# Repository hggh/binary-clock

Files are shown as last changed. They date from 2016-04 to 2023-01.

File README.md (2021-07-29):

# Arduino - binary clock (BCD) with WS2812B

Binary Clock mit WS2812b LED strips

## Bauteile

 * Schwarzes festes Papier (Pappe) Lichtstreifen
 * Ikea Ribba Rahmen, 50x50cm
 * Plexiglas 45% Lichtdurchlässigkeit 50x50cm 2mm
 * schwarze Klebefolie
 * Arduino (Uno oder Nano)
 * 40x WS2812b LEDs (Stips 60 LEDs/m)
 * RTC Modul
 * DCF77 Modul

## Hardware

 * connect color change button to GND and digital pin 6
 * connect led brightness button to GND and digital pin 5
 * connect WS2812b Data In to digital pin 9
 * connect RV8523 RTC to A4(SDA) and A5(SCL)
 * connect DCF77 module to digital pin 2 and digital pin 0

## Weitere Bilder vom Bau

[Weitere Bilder](Pics.md)

## Bild

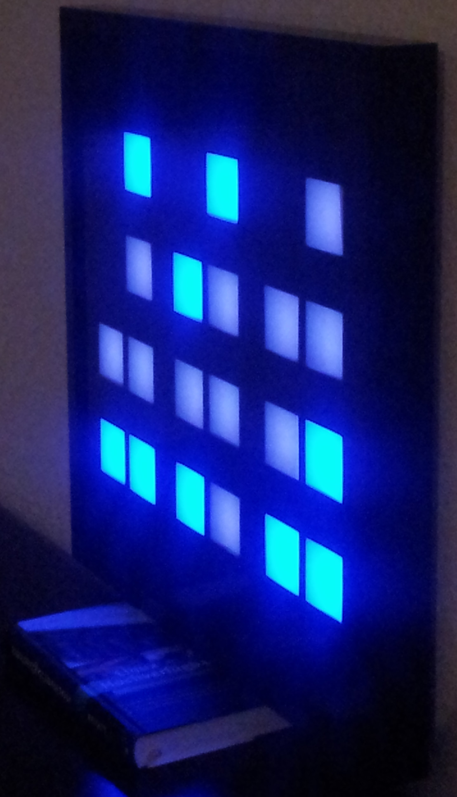
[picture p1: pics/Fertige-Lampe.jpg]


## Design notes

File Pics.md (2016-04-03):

# Bilder vom Bau

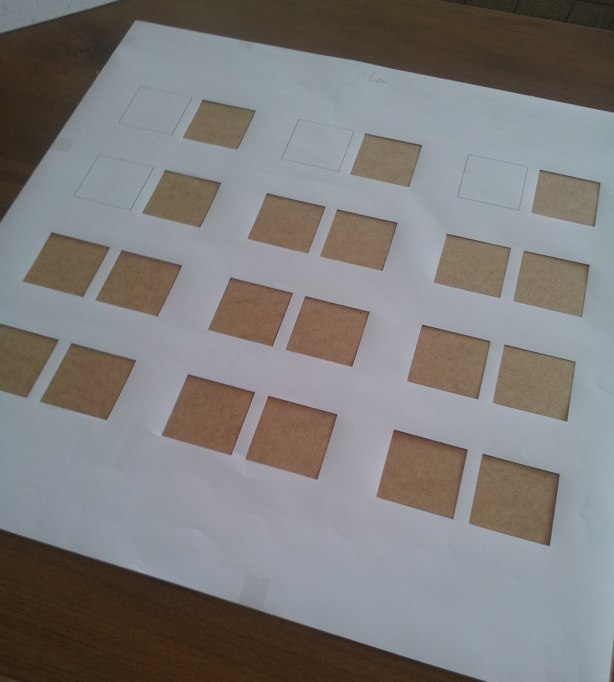
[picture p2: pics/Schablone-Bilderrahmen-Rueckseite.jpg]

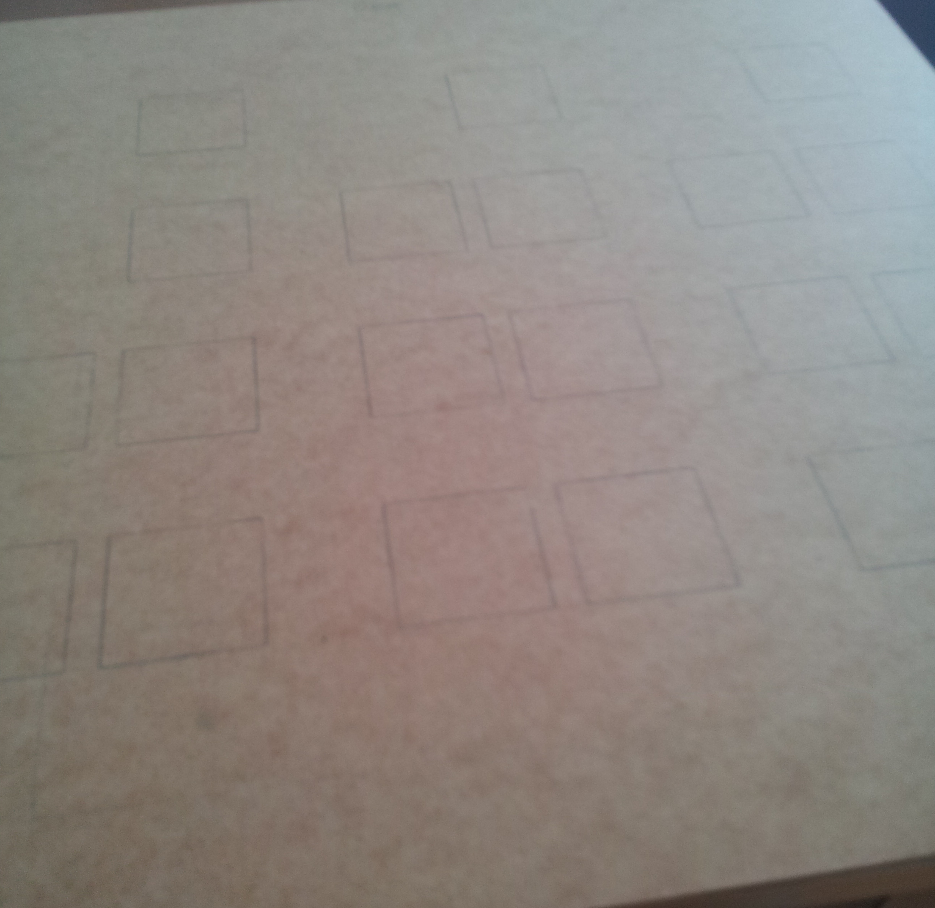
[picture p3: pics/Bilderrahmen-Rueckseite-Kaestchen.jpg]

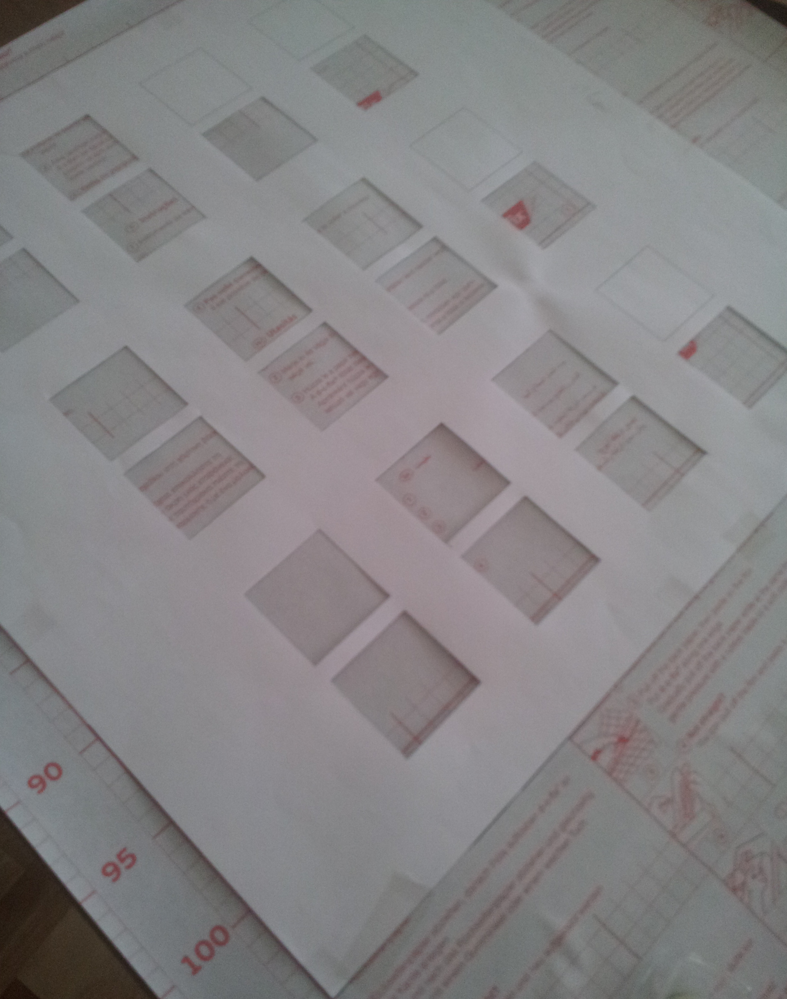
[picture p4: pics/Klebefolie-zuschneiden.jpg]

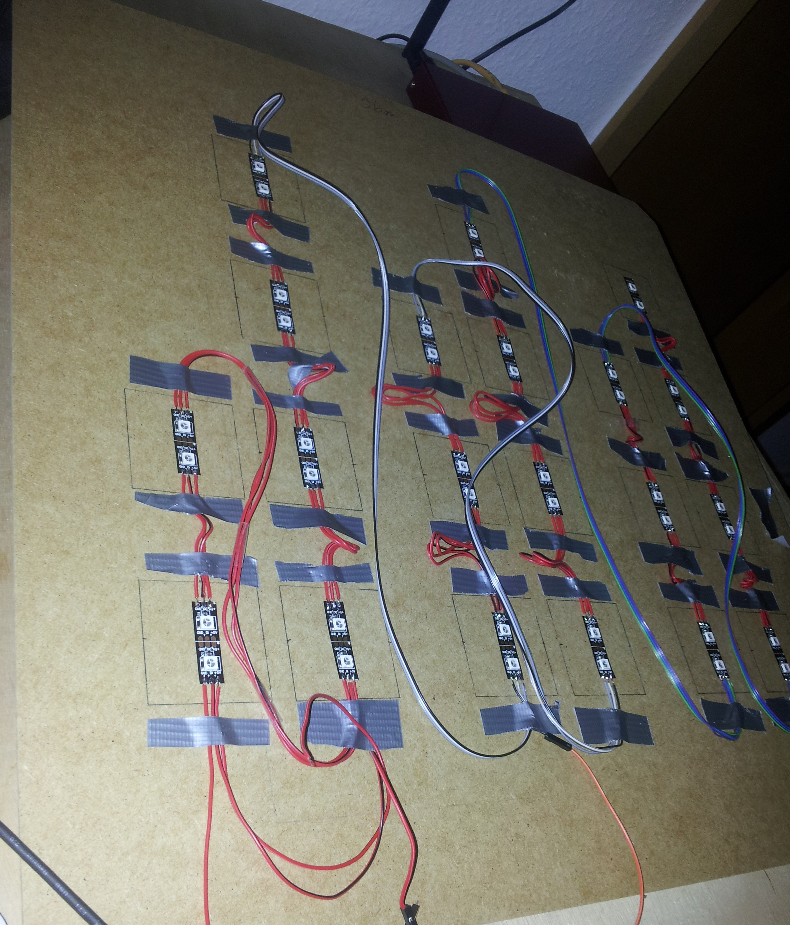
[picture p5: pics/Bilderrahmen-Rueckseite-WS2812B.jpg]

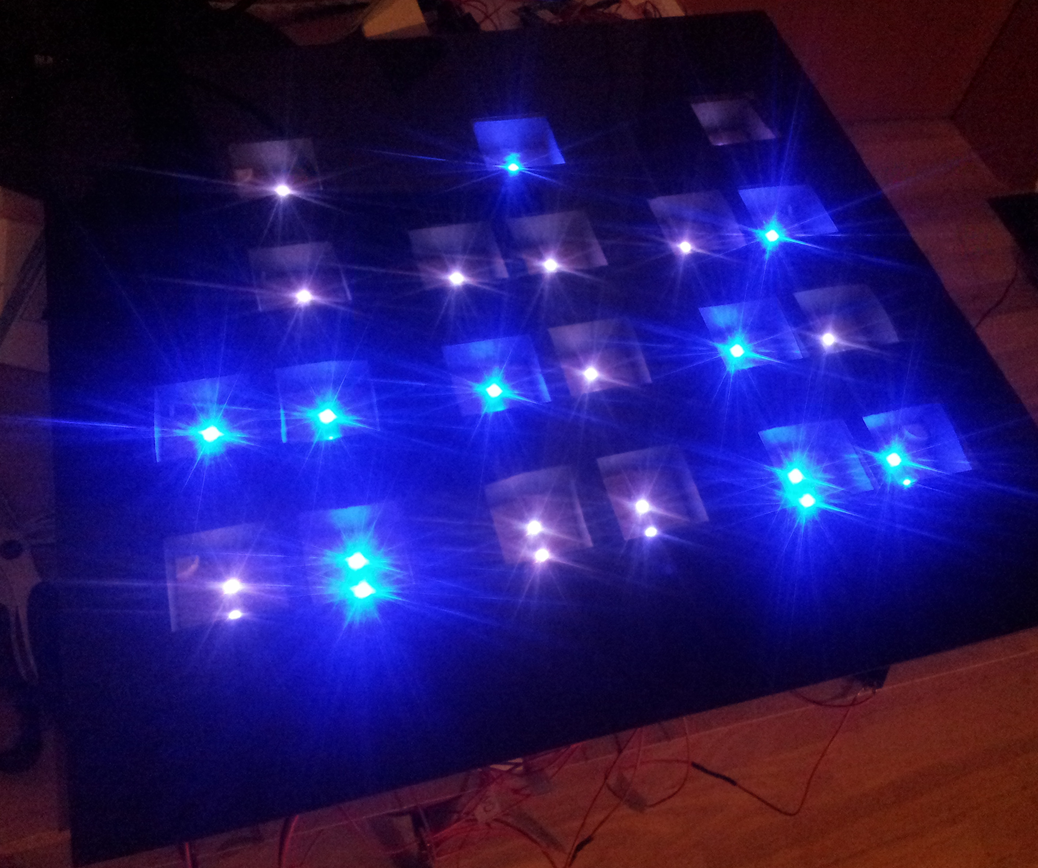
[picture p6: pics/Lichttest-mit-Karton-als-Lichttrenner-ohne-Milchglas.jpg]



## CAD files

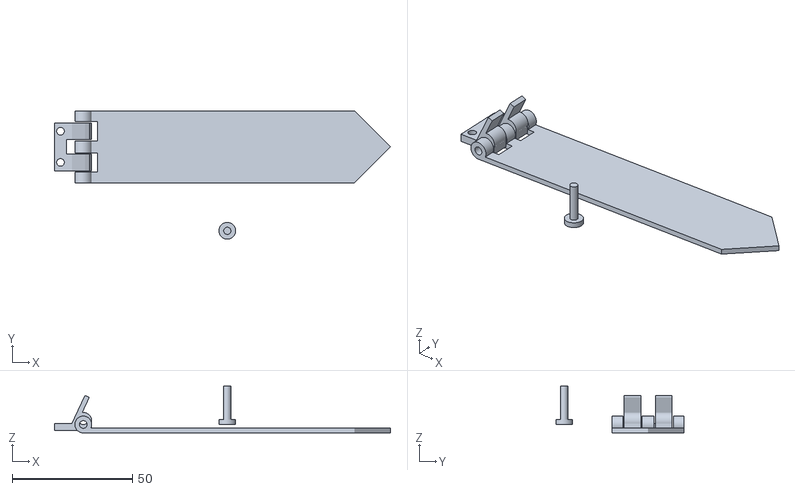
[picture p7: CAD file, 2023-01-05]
3d/holder-back.stl
140.0 x 53.5 x 19.5

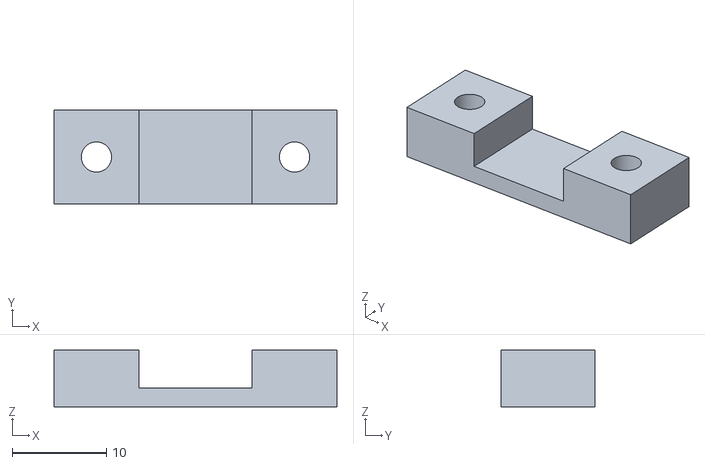
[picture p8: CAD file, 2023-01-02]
3d/ButtonHolder.stl
30.0 x 10.0 x 6.00

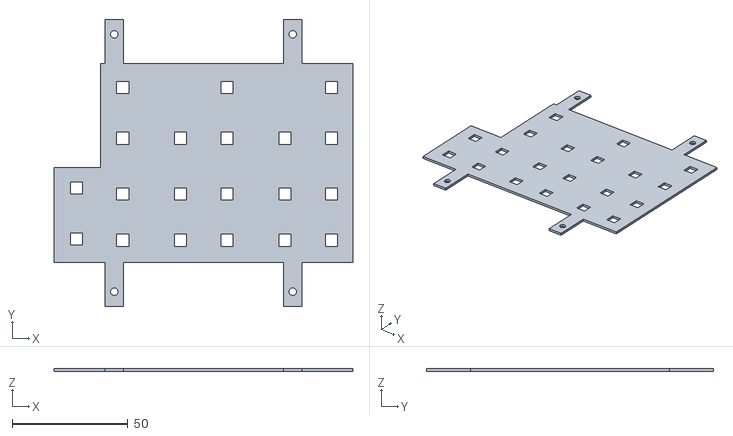
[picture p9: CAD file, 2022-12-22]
3d/led-mounting.stl
129.0 x 124.0 x 1.20

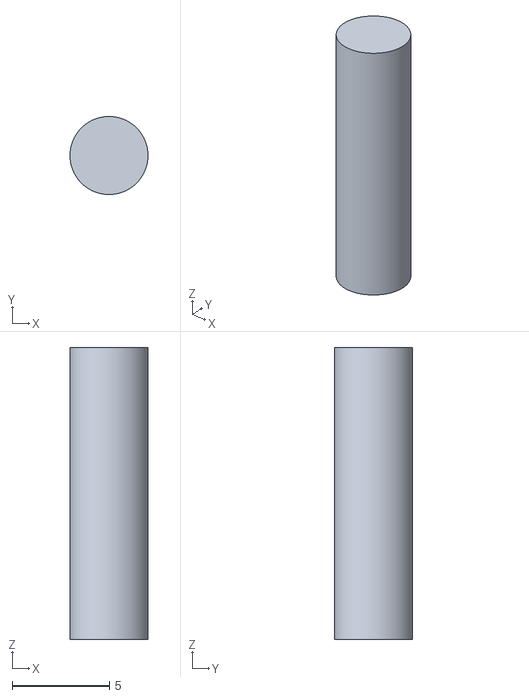
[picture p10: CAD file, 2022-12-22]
3d/wood-connector.stl
4.01 x 4.01 x 15.0

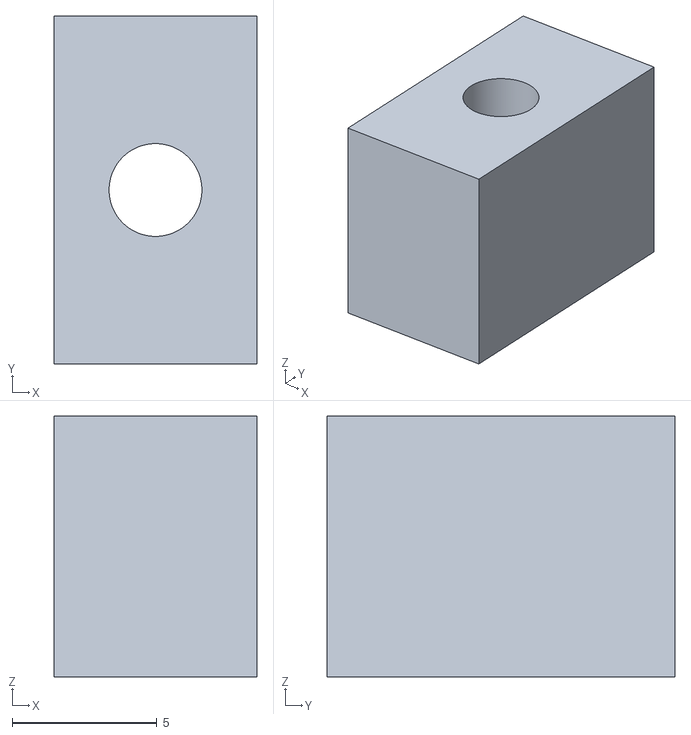
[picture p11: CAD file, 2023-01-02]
3d/led-mounting-screw-holder.stl
7.00 x 12.0 x 9.00

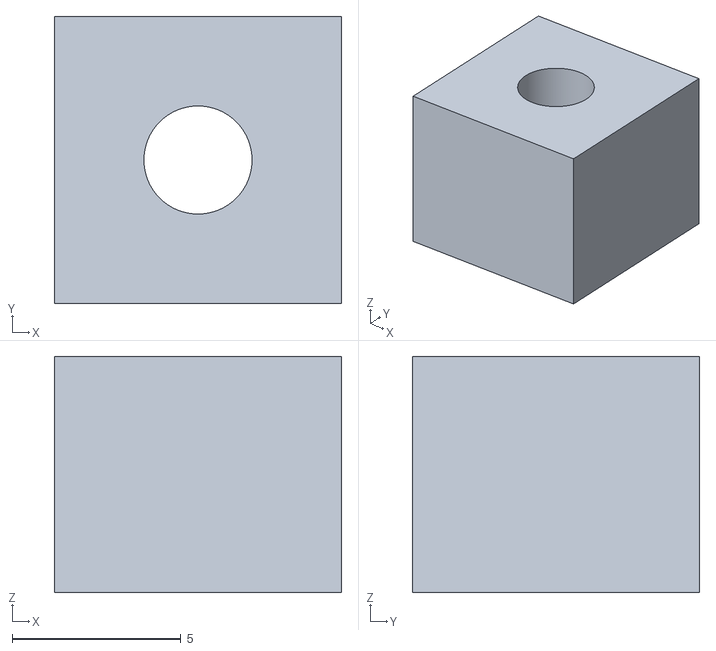
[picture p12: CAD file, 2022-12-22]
3d/screw-holder-inside.stl
8.50 x 8.50 x 7.00

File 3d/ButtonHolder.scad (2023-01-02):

//button 12mm
// hoch = 4mm


difference() {
    cube([30, 10, 2  + 4]);
    translate([9, 0, 2]) cube([12, 10, 10]);
    
    translate([4.5, 5, 0]) {
        cylinder(d=3.2, h=8, $fn=190);
        cylinder(r = 5.5 / 2 / cos(180 / 6) + 0.05, h=3, $fn=6);
    }
    translate([25.5, 5, 0]) {
        cylinder(d=3.2, h=8, $fn=190);
        cylinder(r = 5.5 / 2 / cos(180 / 6) + 0.05, h=3, $fn=6);
    }
}

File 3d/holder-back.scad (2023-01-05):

$fn=190;

difference() {
    union() {
        rotate([270, 0, 0]) cylinder(d=7, h=30);
        translate([0, 0, -3.5]) cube([115 - 2, 30, 2]);
    }
    rotate([270, 0, 0]) cylinder(d=3.2, h=30);
    
    translate([-10, 5-0.5, -5]) cube([16, 7+1, 10]);
    translate([-10, 30 - 8 -5 +0.5, -5]) cube([16, 7+1, 10]);
}

translate([115-2, 0, -3.5]) rotate([0, 0, 45])cube([21.21,21.21, 2]);



translate([60, -20, 0]) {
    cylinder(d=3, h=14 +2);
    cylinder(d=7, h=2);
}


translate([-5, 0, -2.5]) {
    difference() {
        union() {
            translate([-2, 5, 0]) cube([10.4, 7, 3]);
            translate([5, 5, 4]) rotate([270, 0, 0]) cylinder(d=7, h=7);
            translate([5, 30 - 5 -7, 4]) rotate([270, 0, 0]) cylinder(d=7, h=7);
            translate([-2, 30 - 5 -7, 0]) cube([10.4, 7, 3]);
            
        }
        translate([5, 5, 4]) rotate([270, 0, 0]) cylinder(d=3.2, h=7);
        translate([5, 30 - 5 -7, 4]) rotate([270, 0, 0]) cylinder(d=3.2, h=7);
        
        
    }
    translate([2, 5, 2]) {
        rotate([0, -65, 0]) cube([13, 7, 2]);
        translate([0, 13, 0])
        rotate([0, -65, 0]) cube([13, 7, 2]);
    }
    translate([-7, 5, 0]) {
        difference() {
            cube([5, 20, 3]);
            // Montage M3
            translate([2.5, 3.5, 0]) cylinder(d=3.2, h=10);
            translate([2.5, 3.5 + 7 +5+1, 0]) cylinder(d=3.2, h=10);
        }
    }

}

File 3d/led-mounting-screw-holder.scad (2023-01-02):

$fn=190;

difference() {
    cube([7, 12, 9]);
    translate([3.5, 6, 0]) {
        cylinder(d=3.2, h=10);
        rotate([0, 0, 30])cylinder(r = 5.5 / 2 / cos(180 / 6) + 0.05, h=4, $fn=6);
    }
}

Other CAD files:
3d/led-mounting.scad
3d/screw-holder-inside.scad
3d/wood-connector.scad

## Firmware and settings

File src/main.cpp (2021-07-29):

#include <Arduino.h>
#include <TimeLib.h>
#include <Wire.h>

#include <RV8523.h>
#include <FastLED.h>
#include <Bounce2.h>
#include <DCF77.h>

//#define HAS_DCF77

#define LED_CLOCK_COUNT 40   // all LEDs
#define BUTTON_BRIGHTNESS 5 // digital pin 5
#define BUTTON_COLOR 6 // digital pin 6
#define LED_CLOCK_PIN  9     // digital data pin
#define DCF_PIN 2            // Digital Pin Connection pin to DCF 77 device
#define DCF_INTERRUPT 0      // Interrupt number associated with pin

DCF77 DCF = DCF77(DCF_PIN, DCF_INTERRUPT);
RV8523 rtc;
CRGB clock_leds[LED_CLOCK_COUNT];

Bounce2::Button button_brightness = Bounce2::Button();
Bounce2::Button button_color = Bounce2::Button();

const CRGB::HTMLColorCode colors[35] = { CRGB::Crimson,CRGB::Red,CRGB::DarkRed,CRGB::DeepPink,CRGB::OrangeRed,CRGB::Orange,CRGB::Gold,CRGB::Yellow,CRGB::Violet,CRGB::Navy,CRGB::RosyBrown,
CRGB::Fuchsia,CRGB::MediumOrchid,CRGB::BlueViolet,CRGB::Purple,CRGB::Indigo,CRGB::DarkSlateBlue,CRGB::GreenYellow,CRGB::Lime,CRGB::MediumSpringGreen,CRGB::ForestGreen,CRGB::DarkGreen,
CRGB::LightSeaGreen,CRGB::Teal,CRGB::Cyan,CRGB::CadetBlue,CRGB::SteelBlue,CRGB::SkyBlue,CRGB::Blue,CRGB::DarkBlue,CRGB::Chocolate,CRGB::SaddleBrown,CRGB::Maroon,CRGB::DarkSlateGray,CRGB::Brown };

/*
 * Global variables for Loop
 */
time_t time_old;
uint8_t led_brightness = 255;
uint8_t led_color_brightness = 80;
uint8_t led_color_index = 0;
boolean update_leds = false;
CRGB::HTMLColorCode led_color = CRGB::DarkBlue;

/*
 * Set the RTC timer from the time_t struct
 */
void rtc_set_time(time_t time_c) {
  rtc.stop();
  rtc.set(
    second(time_c),
    minute(time_c),
    hour(time_c),
    day(time_c),
    month(time_c),
    year(time_c)
  );
  rtc.start();
}

/*
 * Get the RTC time and return time_t
 */
time_t rtc_get_time() {
  tmElements_t tm;
  uint8_t sec, min, hour, day, month;
  uint16_t year;

  rtc.get(&sec, &min, &hour, &day, &month, &year);

  tm.Second = sec;
  tm.Minute = min;
  tm.Hour = hour;
  tm.Day = day;
  tm.Month = month;
  tm.Year = (year - 1970);
  return makeTime(tm);
}

/*
 * some nice loopings
 */
void leds_do_looping() {
  for (uint8_t i = 0; i < 4; i++) {
    for (uint8_t dot = 0; dot < LED_CLOCK_COUNT; dot++) {
      clock_leds[dot] = CRGB::Blue;
      FastLED.show();
      clock_leds[dot] = CRGB::Red;
      delay(10);
    }
    FastLED.clear();
    FastLED.show();
  }
}

void setup() {
  time_t DCFtime = 0;
  Serial.begin(9600);

  button_brightness.attach(BUTTON_BRIGHTNESS, INPUT_PULLUP);
  button_brightness.interval(25);
  button_brightness.setPressedState(LOW);

  button_color.attach(BUTTON_COLOR, INPUT_PULLUP);
  button_color.interval(25);
  button_color.setPressedState(LOW);

  FastLED.addLeds<NEOPIXEL, LED_CLOCK_PIN>(clock_leds, LED_CLOCK_COUNT);
  FastLED.setBrightness(led_brightness);
  leds_do_looping();
  
  Serial.println("Starting program, fetching now time from DCF77...");

  rtc.set24HourMode();

  // my RTC module has no battery, we get the time every startup from DCF77
  rtc.batterySwitchOver(0);

  DCF.Start();
  delay(100);

  while(DCFtime == 0) {
    Serial.println("Waiting for Time...");
    delay(200);
    DCFtime = DCF.getTime();
  }
  rtc_set_time(DCFtime);
  leds_do_looping();

  /*
  rtc.set(
    0,
    33,
    16,
    5,
    7,
    2014
  );
  rtc.start();
  */
}

void write_time(uint8_t offset_first, uint8_t offset_second, uint8_t number) {
  // split the numer if the first and second
  uint8_t t_first = ((number / 10 ) % 10);
  uint8_t t_second = (number % 10 );
  byte bt_first = t_first;
  byte bt_second = t_second;

  for (uint8_t i=0; i<4; i++) {
    if (bitRead(bt_first, i) == 1) {
      clock_leds[offset_first + i * 2]       = led_color;
      clock_leds[offset_first + (i * 2) + 1] = led_color;
      clock_leds[offset_first + i * 2].nscale8(led_color_brightness);
      clock_leds[offset_first + (i * 2) + 1].nscale8(led_color_brightness);
    }
    else {
      clock_leds[offset_first + i * 2]       = CRGB::Grey;
      clock_leds[offset_first + (i * 2) + 1] = CRGB::Grey;
      clock_leds[offset_first + i * 2].nscale8(20);
      clock_leds[offset_first + (i * 2) + 1].nscale8(20);
    }
  }

  for (uint8_t i=0; i<4; i++) {
    if (bitRead(bt_second, i) == 1) {
      clock_leds[offset_second + i * 2 ]     = led_color;
      clock_leds[offset_second + i * 2 + 1]  = led_color;
      clock_leds[offset_second + i * 2 ].nscale8(led_color_brightness);
      clock_leds[offset_second + i * 2 + 1].nscale8(led_color_brightness);
    }
    else {
      clock_leds[offset_second + i * 2 ]     = CRGB::Grey;
      clock_leds[offset_second + i * 2 + 1]  = CRGB::Grey;
      clock_leds[offset_second + i * 2 ].nscale8(20);
      clock_leds[offset_second + i * 2 + 1].nscale8(20);
    }
  }
}

void loop() {
  button_brightness.update();
  button_color.update();

  if (button_brightness.pressed()) {
    update_leds = true;

    led_color_brightness += 5;
    Serial.print("Light: ");
    Serial.println(led_color_brightness);
  }

  if (button_color.pressed()) {
    update_leds = true;

    led_color_index++;
    if (led_color_index > 34) {
      led_color_index = 0;
    }
    led_color = colors[led_color_index];
    Serial.print("Color: ");
    Serial.println(led_color);
  }

  // check if one second is gone, we need to update the LEDs
  time_t time_current = rtc_get_time();
  if (time_old != time_current || update_leds == true) {
    update_leds = false;

    FastLED.clear();
    time_old = time_current;
    Serial.print("Time: ");
    Serial.println(time_current);

    write_time( 0,  4, hour(time_current));
    write_time(12, 18, minute(time_current));
    write_time(26, 32, second(time_current));

    // write LEDs....
    FastLED.show();
  }
}

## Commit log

2015-07-05 do not loop LEDs while waiting for DCF77, seems that both active does not work. dcf7 never gets a signal
    [sketch_jul04a.ino]
2015-07-06 changed to another dht lib, try to correct errors on sensor read
    [sketch_jul04a.ino]
2015-07-06 added switch to on/off the display
2015-07-25 added papercut to easy draw it to the back of the frame
2015-07-25 updated paper to arrange LEDs
2015-07-25 added hour and minute leds and display time
2015-08-01 added LEDs for display seconds
2015-08-25 added missing license information
    [sketch_jul04a.ino]
2015-10-11 added digital button
2015-10-11 added button mode analog
2021-07-29 update to current arduino; change to platformio
2022-12-22 add new clock idea with wood
    [led-mounting.scad, led-mounting.stl, screw-holder-inside.scad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]
2023-01-02 add button, mountings
    [ButtonHolder.scad, ButtonHolder.stl, led-mounting-screw-holder.scad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]
2023-01-05 add holder back, add back cutout update drawing
    [holder-back.scad, holder-back.stl]
